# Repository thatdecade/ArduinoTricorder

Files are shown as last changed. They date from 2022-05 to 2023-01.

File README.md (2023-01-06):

# ArduinoTricorder
Interactive Tricorder Prop with real environmental sensors

Based on the original work by lambtor: https://github.com/lambtor/ArduinoTricorder

# Features

* Animated Lights and Sounds, Interactive Menus
* Thermal Camera (MLX90640)
* Climate Sensors: Humidity (SHT31), Temperature and barometric pressure (BMP280)
* Color Sensor and Distance Measurement (APDS9960)
* Microphone (PDM) FFT spectrum
* Auto Sleep when Door is Closed, uses Magnetometer (LIS3MDL)

# Usage

On Power up, the main screen is displayed and the sound effects start.  

* To navigate the info pages, press left or right.  Pressing center goes home.
* To toggle sound effects, hold the left button.
* Close the lid or wait 10 mins to put to sleep, low power mode.  Open the lid or press a button to wake up.

Thermal Camera: To access the video, press the button marked User SW on the Feather board.  If you did not install the thermal camera, the tricorder will display an error message.
Press the center button to return home.

# Part List

TBD

# 3D Printing

The case assembly notes are on printables: https://www.printables.com/model/225964-printability-remix-of-arduino-tricorder

# Wiring Diagram

Battery, Charger Jack, and Power Switch not shown.  See Adafruit Feather nRF52840 Sense docs.

I used a 2500mAh battery, but smaller would work fine too.  1000mAh - 2500mAh is recommended.

arduinotricorder_fritzing_diagram_bb

If you want to change any wires, use the pinmap.h file.  

# Software Setup

Follow the adafruit guide for setting up the Feather nRF52840 board package in Arduino. Then begin installing the libraries.
https://learn.adafruit.com/adafruit-feather-sense/arduino-support-setup

1. Copy the MLX90640_API folder from this repo's libraries folder to your arduino's libraries folder.  If you are unsure where this is, open Preferences from the Arduino File menu and look for the sktechbook location. Mine is My Documents\Arduino\libraries.
1. Install the following lilbraries.  Start with the latest versions.
> * Adafruit NeoPixel version 1.10.6
> * Adafruit TinyUSB Library version 1.7.0
> * Adafruit GFX Library version 1.11.3
> * Adafruit BusIO version 1.14.1
> * Adafruit ST7735 and ST7789 Library 
> * Adafruit APDS9960 Library version 1.2.2
> * Adafruit BMP280 Library version 2.6.6
> * Adafruit Unified Sensor version 1.1.6
> * Adafruit SHT31 Library version 2.2.0
> * nRF52840 PDM - Adafruit Fork version 1.0
> * Adafruit Zero FFT Library version 1.0.4
> * Adafruit LIS3MDL version 1.2.1
> * DFRobotDFPlayerMini version 1.0.5
3. Hit the Compile to test everything is as it should be.  If you get any errors, try switching to the version listed above.
4. Plug in the arduino to USB, and select Adafruit Feather nRF52840 Sense as the board, then select the port.
5. Hit Upload.

If all went well, you should see the display come alive.

# Bugs

* I used D13 for the BIO button input and needed to remove the Arduino's D13 onboard LED.  

On the Adafruit Feather nRF52840 Sense board, D13 is wired to an onboard LED (similar to other arduino boards).  D13 worked at first using INPUT_PULLUP, but eventually stopped working.  I measured the voltage on this pin at 1.9V when the button was unpressed, and 0.2V for pressed.  The nRF52840 requires at least 0.7xVcc to detect a digital high.  1.9V < 2.3V, so the chip thought the button was stuck pressed.  The LED + Resistor and INPUT_PULLUP were creating a voltage clamp at the diode's Forward Voltage.

My fix was unsoldering the D13 LED.  A better fix would be moving the BIO button input wire and reserving D13 as output only.

* Communication with the DFPlayer is inconsistant.

Likely due to me using a clone of the DFPlayer.  Work around is for the arduino to query the status from the DFPlayer every 500ms, then if the player is not playing when it should (or vice versa) we send the play/stop command again.  So if there is a glitch in the audio start / loop / stop, it is fixed quickly.

* Speaker Volume and Screen Flicker, reduce volume and use a larger battery

When the DFPlayer is set to max volume and the tricorder is powered by USB, I noticed the screen flickering from the speaker amp.  Switching to battery, the screen appears ok.

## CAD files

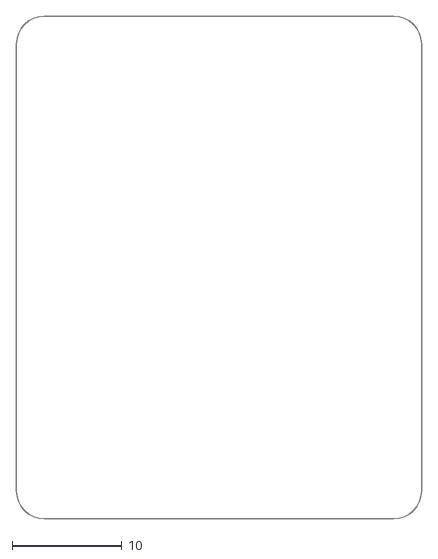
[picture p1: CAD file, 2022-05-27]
ShellModels/Adafruit 1.69in 280x240 Round Rectangle TFT.dxf
36.8 x 45.7

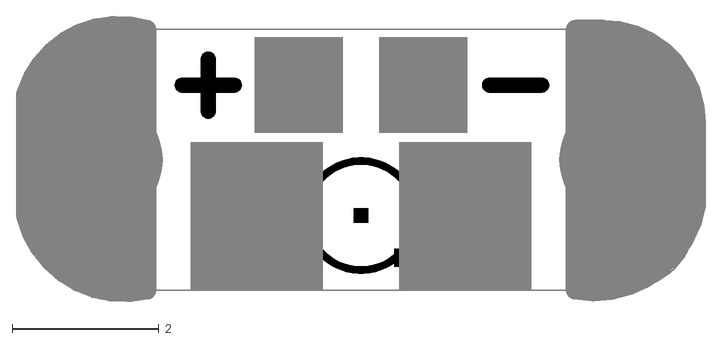
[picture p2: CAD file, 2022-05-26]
ShellModels/Adafruit LED Sequin.dxf
9.40 x 3.90

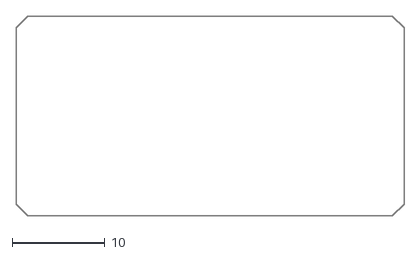
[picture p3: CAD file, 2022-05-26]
ShellModels/ButtonPCB.dxf
41.9 x 21.6

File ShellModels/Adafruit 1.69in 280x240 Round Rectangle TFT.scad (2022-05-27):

margin_for_error = 0.2;

//display_pcb();
//$fn=25;

module display_pcb()
{
    //scale(1.001)
    
    translate([-38.1/2,-45.72/2,1.6/2])
    translate([1.27/2,-1,0])
    difference()
    {
        //OUTLINE
        translate([-1.27,1,0])
        linear_extrude(height = 1.6, center = true, convexity = 10) import("Adafruit 1.69in 280x240 Round Rectangle TFT.dxf");
        
        //HOLES
        //translate([2.25,43.18,0]) cylinder(r=1.2, h=2, center=true);
        //translate([34.0,43.18,0]) cylinder(r=1.2, h=2, center=true);
        //translate([34.0,4.2,0]) cylinder(r=1.2, h=2, center=true);
        //translate([2.25,4.2,0]) cylinder(r=1.2, h=2, center=true);
    }

    //LCD
    fast_rounded_box([30,38,5.4], 4);
}

module fast_rounded_box(size, radius)
{
    height = size[2];
    linear_extrude(height = height)
    projection(cut = true)
    roundedRectangle([size[0]-radius,size[1]-radius,0], radius);
}

module roundedRectangle(size, radius, frontTaper = 0) {
    // https://www.reddit.com/r/openscad/comments/bfx897/comment/elhugtd/
    
    x = size[0];
    y = size[1];
    z = size[2];

    hull() {
        cornerSphere([(-x/2)+(radius/2), (-y/2)+(radius/2) - frontTaper, z], radius);
        cornerSphere([(x/2)-(radius/2), (-y/2)+(radius/2) - frontTaper, z], radius);
        cornerSphere([(-x/2)+(radius/2), (y/2)-(radius/2), z], radius);
        cornerSphere([(x/2)-(radius/2), (y/2)-(radius/2), z], radius);
    }
}

module cornerSphere(location, radius) {
    translate(location) sphere(r=radius);
}

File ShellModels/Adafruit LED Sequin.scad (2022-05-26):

margin_for_error = 0.2;

module led_sequin()
{
    scale(1.01)
    {
        //OUTLINE
        linear_extrude(height = 1.6, center = true, convexity = 10) import("Adafruit LED Sequin.dxf");

        //LED
        translate([0,-0.762,1.6-0.55]) cube([3.2+margin_for_error,1.6+margin_for_error,0.55], center=true);

        //RESISTOR
        translate([0,1.016,1.6-0.55]) cube([1.6+margin_for_error,0.8+margin_for_error,0.55], center=true);

        //WIRES
        translate([-3.556,0,1.6-0.5]) cylinder(d=1,h=1, center=true, $fn=10);
        translate([ 3.556,0,1.6-0.5]) cylinder(d=1,h=1, center=true, $fn=10);
    }
}

//led_sequin();

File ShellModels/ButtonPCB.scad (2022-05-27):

margin_for_error = 0.2;

//button_pcb();


module button_pcb()
{
    scale(1.01)
    difference()
    {
        translate([-41.91/2,-21.59/2,0])
        {
            //OUTLINE
            linear_extrude(height = 1.6, center = true, convexity = 10) import("ButtonPCB.dxf");

            translate([0,0,1.6-0.55])
            {
            //LEDs
            translate([9.525, 14.986,0]) button_side_led();
            translate([22.606,14.986,0]) button_side_led();
            translate([35.56, 14.986,0]) button_side_led();

            //BUTTONS
            translate([9.398, 8.382,0]) button_button();
            translate([22.479,8.382,0]) button_button();
            translate([35.56, 8.382,0]) button_button();

            //WIRES
            translate([39.37,20.32,0]) button_spaced_wire_connector();
            }
        }
        
        //screw holes
        translate([-41.91/2,-21.59/2,0])
        translate([0,0,1.6-0.55])
        {
            translate([16.0655, 14,0]) cylinder(d=3.75, h=4, center=true);
            translate([29.083, 14,0]) cylinder(d=3.75, h=4, center=true);
        }
    }
}

module button_side_led()
{
    cube([3.98+margin_for_error,1.7+margin_for_error,2+margin_for_error], center=true);
}

module button_button()
{
            translate([0,0,+0.5]) cube([11.4+margin_for_error,1.6+margin_for_error,1.6], center=true);
            translate([0,0,1.9]) cube([6+margin_for_error,3.5+margin_for_error,4.57], center=true);
}

module button_spaced_wire_connector()
{
        button_wire_spacing = 2.54;
        translate([-button_wire_spacing*0,0,0]) cylinder(d=1,h=1, center=true, $fn=10);
        translate([-button_wire_spacing*1,0,0]) cylinder(d=1,h=1, center=true, $fn=10);
        translate([-button_wire_spacing*2,0,0]) cylinder(d=1,h=1, center=true, $fn=10);
        translate([-button_wire_spacing*3,0,0]) cylinder(d=1,h=1, center=true, $fn=10);
        translate([-button_wire_spacing*4,0,0]) cylinder(d=1,h=1, center=true, $fn=10);
        translate([-button_wire_spacing*5,0,0]) cylinder(d=1,h=1, center=true, $fn=10);
        translate([-button_wire_spacing*6,0,0]) cylinder(d=1,h=1, center=true, $fn=10);
        translate([-button_wire_spacing*7,0,0]) cylinder(d=1,h=1, center=true, $fn=10);
        translate([-button_wire_spacing*8,0,0]) cylinder(d=1,h=1, center=true, $fn=10);
}

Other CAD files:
ShellModels/tricorder_body.scad
ShellModels/tricorder_hinge.scad

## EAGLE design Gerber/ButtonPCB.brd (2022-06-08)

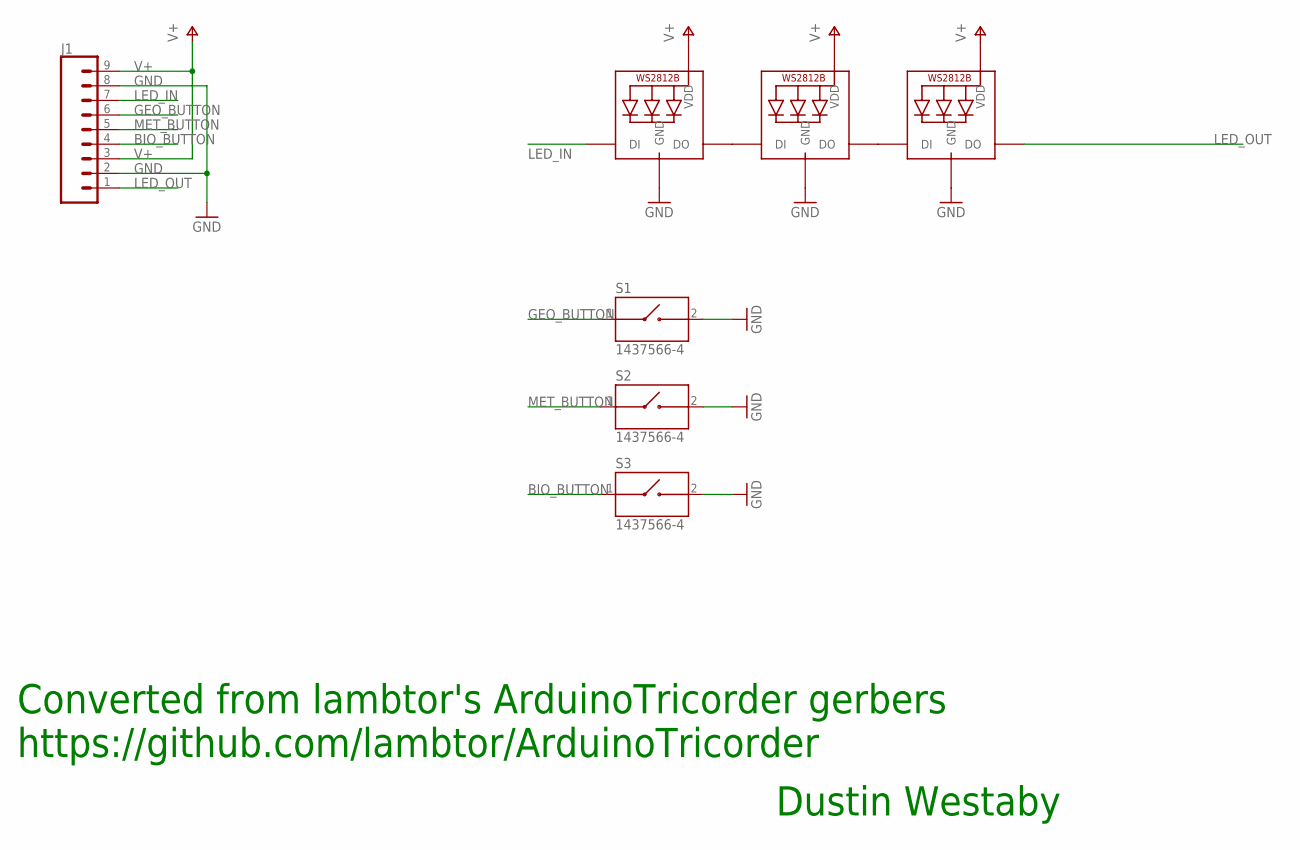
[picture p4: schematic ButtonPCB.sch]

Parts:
J1: CONN_09; 1X09
LED1, LED2, LED3: WS2812B_4020
S1, S2, S3: 1437566-4; SW_1437566-4

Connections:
BIO_BUTTON: J1.4, S3.1
GEO_BUTTON: J1.6, S1.1
GND: J1.2, J1.8, LED1.4 (GND), LED2.4 (GND), LED3.4 (GND), S1.2, S2.2, S3.2
LED_IN: J1.7, LED2.1 (DI)
LED_OUT: J1.1, LED3.3 (DO)
MET_BUTTON: J1.5, S2.1
unnamed: LED1.1 (DI), LED2.3 (DO)
unnamed: LED1.3 (DO), LED3.1 (DI)
V+: J1.3, J1.9, LED1.2 (VDD), LED2.2 (VDD), LED3.2 (VDD)

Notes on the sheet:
Converted from lambtor's ArduinoTricorder gerbers
https://github.com/lambtor/ArduinoTricorder
Dustin Westaby

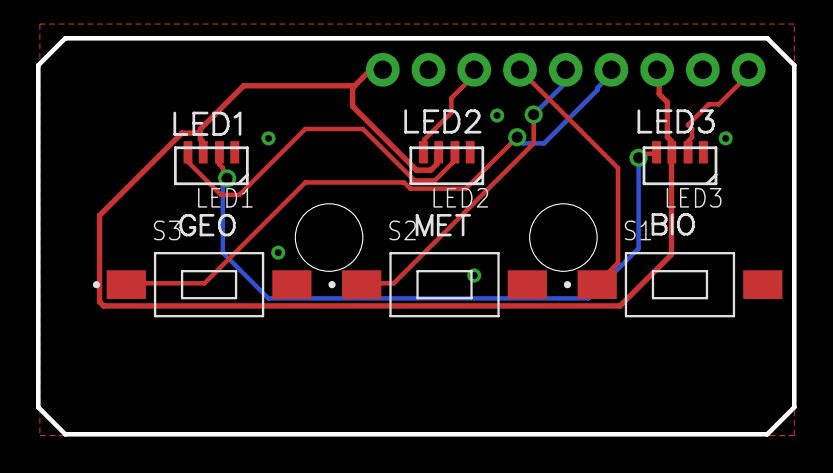
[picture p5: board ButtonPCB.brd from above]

Board: 2 copper layers, 42.0 x 22.0 mm, 7 parts (1 on the bottom side), 9 nets.

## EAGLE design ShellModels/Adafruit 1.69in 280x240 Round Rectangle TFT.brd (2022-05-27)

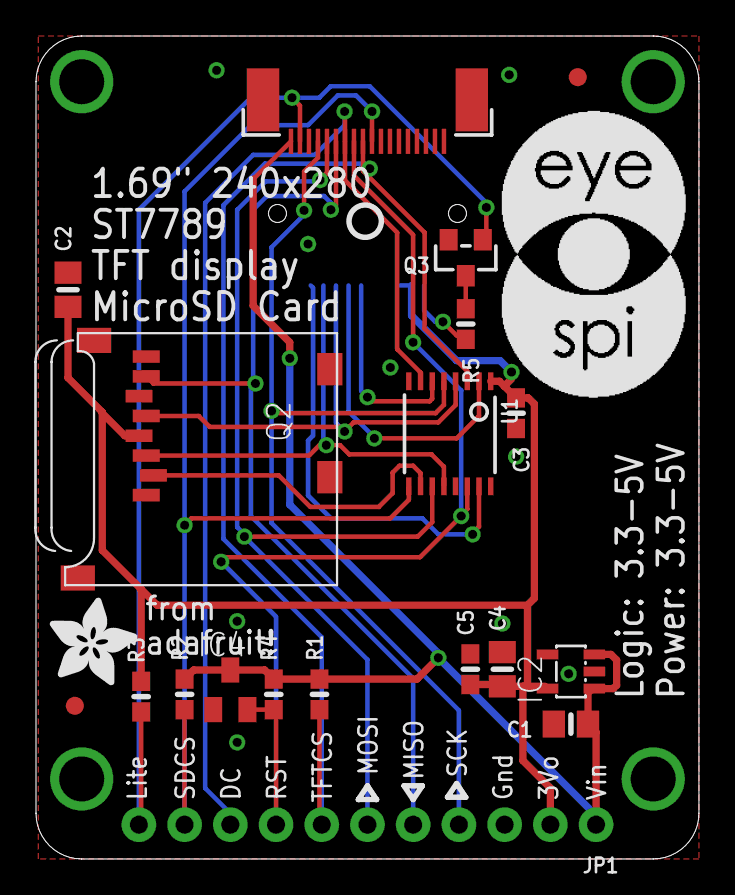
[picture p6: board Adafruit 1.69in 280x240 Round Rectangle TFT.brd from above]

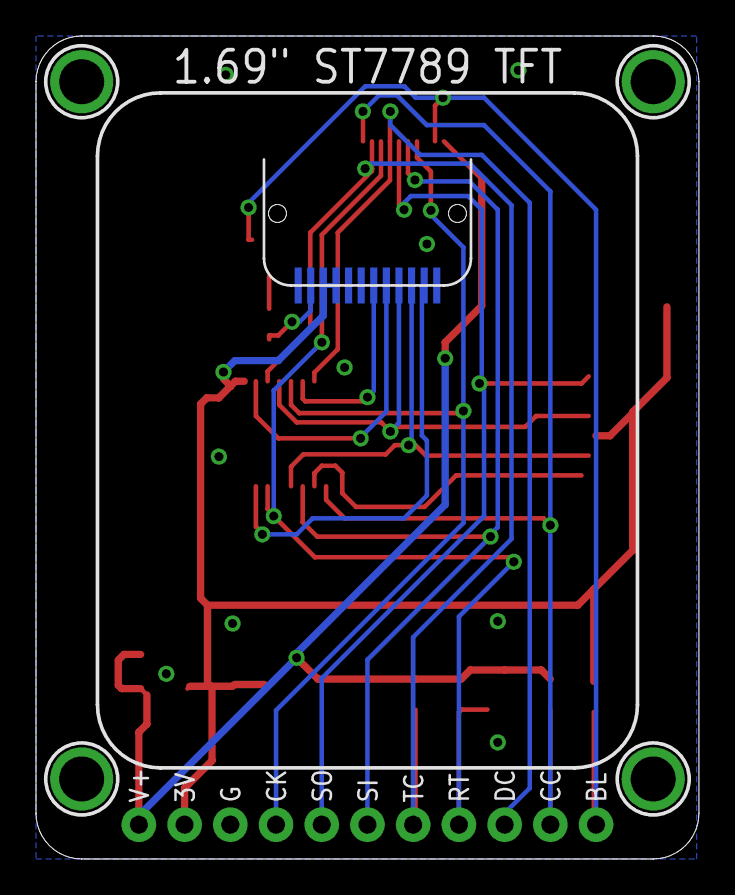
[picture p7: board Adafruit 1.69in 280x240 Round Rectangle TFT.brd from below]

Board: 2 copper layers, 36.8 x 45.7 mm, 27 parts (5 on the bottom side), 19 nets.

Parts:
C1, C2, C4: 10uF; 0805-NO
C3, C5: 0.1uF; 0603-NO
DISP1: DISP_LCD_GENERIC_SPI_1.69_WRAPUNDER; TFT_1.69IN_240X280_12P
IC2: AP2112; SOT23-5L
IC4: APX803-SAG; SOT23
JP1: 1X11_ROUND_76
Q2: MICROSD
Q3: BSS138; SOT23-WIDE
R1, R2, R3, R4: 10K; 0603-NO
R5: 10; 0603-NO
U1: 74HC4050PWR; TSSOP16
U$1: ADAFRUIT_5MM
U$2: PCBFEAT-REV-040
U$4, U$5: FIDUCIAL_1MM
U$7, U$8, U$9, U$10: MOUNTINGHOLE2.5; MOUNTINGHOLE_2.5_PLATED
U$19: EYESPI_LOGO
X1: EYE_SPI_DISPLAY_FLIP; EYE_SPI_DISPLAY_BOTCONTACT

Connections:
+3V3: C2.1, C3.1, C4.1, C5.1, DISP1.3, DISP1.4, IC2.5, JP1.2, Q2.4, R3.2, U1.1
CARDCS: JP1.10, R2.1, U1.9, X1.10
CARDCS_3V: Q2.2, U1.10
GND: C1.2, C2.2, C3.2, C4.2, C5.2, DISP1.1, DISP1.5, DISP1.6, DISP1.12, IC2.2, IC4.1, JP1.3, Q2.6, Q2.MT1, Q2.MT2, Q3.2, U1.8, X1.3, X1.SUPPORT1, X1.SUPPORT2
LEDK: DISP1.2, R5.2
LITE: JP1.11, Q3.1, R3.1, X1.2
MISO: JP1.5, Q2.7, X1.6
MOSI: JP1.6, U1.11, X1.5
MOSI_3V: DISP1.10, Q2.3, U1.12
unnamed: Q3.3, R5.1
SCK: JP1.4, U1.5, X1.4
SCK_3V: DISP1.9, Q2.5, U1.4
TFTCS: JP1.7, R1.1, U1.3, X1.9
TFTCS_3V: DISP1.8, U1.2
TFTDC: JP1.9, U1.7, X1.7
TFTDC_3V: DISP1.7, U1.6
TFTRST: IC4.2, JP1.8, R4.1, U1.14, X1.8
TFTRST_3V: DISP1.11, U1.15
VIN: C1.1, IC2.1, IC2.3, IC4.3, JP1.1, R1.2, R2.2, R4.2, X1.1

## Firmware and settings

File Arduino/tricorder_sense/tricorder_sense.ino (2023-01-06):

#include <Adafruit_NeoPixel.h>
#include <SPI.h>
#include <Adafruit_GFX.h>     // Core graphics library
#include <Adafruit_ST7789.h>  // Hardware-specific library for ST7789
#include <string.h>
#include <Adafruit_APDS9960.h>  //RGB, light, proximity, gesture sensor
#include <Wire.h>
#include <Adafruit_BMP280.h>  //altitude, barometer
#include <Adafruit_SHT31.h>   //temp, humidity
#include <Adafruit_Sensor.h>
#include <PDM.h>              // Microphone
#include <Adafruit_ZeroFFT.h> // Audio spectrum
#include <MLX90640_API.h>     //Thermal Camera
#include <MLX90640_I2C_Driver.h>
#include <Adafruit_LIS3MDL.h> //magnetometer, for door close detection
//#include <Adafruit_LSM6DS33.h> //Accel + Gyro (unused)

#include "pinmap.h" // go here to set your own pin definitions
#include "buttons.h"
#include "menu_navigation.h"
#include "sleep_timer.h"
#include "audio_player.h"

#if defined(USE_TINYUSB)
#include <Adafruit_TinyUSB.h> // for Serial, version 1.7.0
#endif

//comment these out for faster startup and timers
//#define DEBUGSERIAL 1
//#define DEBUGMAGNET_ON_SERIAL 1

 
// need to remove hyphens from header filenames or exception will get thrown
#include "Fonts/lcars15pt7b.h"
#include "Fonts/lcars11pt7b.h"

#define SCAN_LED_BRIGHTNESS   (32)

#define NEOPIXEL_BRIGHTNESS     (64)

//ledPwrStrip - cover and door pixels.  This structure defines the order of the LEDs on the string
typedef enum
{ //re-arrange as need based on your wiring
  PWR_PIXEL_POSITION = 0, // POWER LED
  GEO_PIXEL_POSITION,     // BUTTON LED
  MET_PIXEL_POSITION,     // BUTTON LED
  BIO_PIXEL_POSITION,     // BUTTON LED
  ID_PIXEL_POSITION,      // DOOR LED
  EMRG_PIXEL_POSITION,    // DOOR LED

  POWERSTRIP_LED_COUNT, //must be last
} strip_led_positions;

//ledBoard - front pixels
#define BOARD_PIXEL_POSITION 0

//system os version #. max 3 digits
#define DEVICE_VERSION      "0.94"

//theme definition: 0 = TNG, 1 = DS9, 2 = VOY
#define UX_THEME                  (0)

#define THERMAL_CAMERA_PORTRAIT   (1)

//uncomment this line to have raw magnetometer z value displayed on home screen
//#define MAGNET_DEBUG

//the -700 threshold was based on resolution of 10, or 1024 max
//-10000 is based on the analog resolution required by battery pin (-32768 to 32768 range)
//this is intended for the z index reading of magnetometer (negative means field is below the board)
#define mnMagnetSleepThreshold -10000
#define mnMagnetAproachingThreshold 0

#if UX_THEME == 0
  // TNG colors here
  #define color_SWOOP       0xF7B3
  #define color_MAINTEXT    0x9E7F
  //#define color_MAINTEXT    0xC69F
  #define color_LABELTEXT   0x841E
  #define color_HEADER      0xFEC8
  #define color_TITLETEXT   0xFEC8
  //196,187,145
  #define color_LABELTEXT2  0xC5D2
  //204,174,220
  #define color_LABELTEXT3  0xCD7B
  #define color_LABELTEXT4  0xEE31
  #define color_LEGEND      0x6A62
  //210,202,157
  #define color_FFT         0xDEB5
#elif UX_THEME == 1
  // ds9
  #define color_SWOOP       0xD4F0
  #define color_MAINTEXT    0xBD19
  #define color_LABELTEXT   0x7A8D
  #define color_HEADER      0xECA7
  #define color_TITLETEXT   0xC3ED
  //to-do: find fitting options for these to mesh with ds9
  #define color_LABELTEXT2  0xC5D2
  #define color_LABELTEXT3  0xCD7B
  #define color_LABELTEXT4  0xEE31
  #define color_LEGEND      0x6A62
  #define color_FFT         0xDEB5
#elif UX_THEME == 2
  // voy
  #define color_MAINTEXT    0x9E7F
  #define color_SWOOP       0x7C34
  #define color_LABELTEXT   0x9CDF
  #define color_HEADER      0xCB33
  #define color_TITLETEXT   0xFFAF
  //to-do: find fitting options for these to mesh with voy
  #define color_LABELTEXT2  0xC5D2
  #define color_LABELTEXT3  0xCD7B
  #define color_LABELTEXT4  0xEE31
  #define color_LEGEND      0x6A62
  #define color_FFT         0xDEB5
#endif

#define color_REDLABELTEXT     0xE000
#define color_REDDARKLABELTEXT 0x9800
#define color_REDDATATEXT      0xDEFB

//use labeltext3 for servo ltpurple
#define color_SERVOPINK     0xFE18
#define color_SERVOPURPLE   0x83B7


#define RGBto565(r,g,b) ((((r) & 0xF8) << 8) | (((g) & 0xFC) << 3) | ((b) >> 3))

Adafruit_NeoPixel ledPwrStrip(POWERSTRIP_LED_COUNT, NEOPIXEL_CHAIN_DATAPIN, NEO_GRB + NEO_KHZ800);
Adafruit_NeoPixel ledBoard(1, NEOPIXEL_BOARD_LED_PIN, NEO_GRB + NEO_KHZ800);

uint32_t neoPixelBlack  = ledPwrStrip.Color(   0,   0,   0);
uint32_t neoPixelBlue   = ledPwrStrip.Color(   0,   0, 128);
uint32_t neoPixelGreen  = ledPwrStrip.Color(   0, 128,   0);
uint32_t neoPixelYellow = ledPwrStrip.Color( 112, 128,   0);
uint32_t neoPixelOrange = ledPwrStrip.Color( 128,  96,   0);
uint32_t neoPixelRed    = ledPwrStrip.Color( 128,   0,   0);
uint32_t neoPixelWhite  = ledPwrStrip.Color( 255, 255, 255);

//  2.0" IS THE BOARD - this call uses hardware SPI
Adafruit_ST7789   tft = Adafruit_ST7789(TFT_CS, TFT_DC, TFT_RST);
//create sensor objects
Adafruit_APDS9960 oColorSensor;
Adafruit_BMP280   oTempBarom;
Adafruit_SHT31    oHumid;
Adafruit_LIS3MDL  oMagneto;
paramsMLX90640    moCameraParams;

int mnCurrentProfileRed   = 0;
int mnCurrentProfileGreen = 0;
int mnCurrentProfileBlue  = 0;

String msCurrentProfileName = "";

int mnEMRGCurrentStrength =   8;

bool mbLEDIDSet = false;

/* Timer Values */
#define POWER_LED_INTERVAL        8000  //power interval doesn't need to check more than every 30 seconds
#define BOARD_LED_INTERVAL        5000
#define ID_LED_INTERVAL           1000
#define EMRG_LED_INTERVAL           33  //30Hz
#define EMRG_LED_BREATHING_RATE   1500
#define BUTTON_LED_INTERVAL        100

#define RGB_SCAN_INTERVAL         5000
#define MIC_READ_INTERVAL         3000
#define CLIMATE_SCAN_INTERVAL     2000
#define MAGNET_READ_INTERVAL      1000
#define HOME_UPDATE_INTERVAL      1000
#define AUDIO_UPDATE_RATE          500
#define BOARD_RED_LED_INTERVAL     350
#define BOARD_BLUE_LED_INTERVAL    250
#define LEFT_SCANNER_LED_INTERVAL  200
#define DISPLAY_UPDATE_RATE        100 // 10hz
#define THERMAL_CAMERA_INTERVAL     50 // twice per display refresh
#define SERVO_DRAW_INTERVAL         38
#define BAR_DRAW_INTERVAL            9
//17 ms is 60fps. setting this to 120fps, at least for initial crawl

/* EMRG LED Animation */
#define EMRG_MIN_BRIGHTNESS   50
#define EMRG_MAX_BRIGHTNESS  212
#define EMRG_BREATH_INCREMENT ((EMRG_MAX_BRIGHTNESS - EMRG_MIN_BRIGHTNESS) / (EMRG_LED_BREATHING_RATE / EMRG_LED_INTERVAL))
bool mbEMRGdirection = false;

int mnLeftLEDCurrent = 0;

/* Scroll wheel colors and names */
#define NUMBER_ID_COLORS 8
                    //colors range is purple > blue > green > yellow > orange > red  > pink > white
const uint32_t mnIDLEDColorscape[NUMBER_ID_COLORS] = {0x8010, 0x0010, 0x0400, 0x7C20,  0x8300,  0x8000,0x8208,0x7C30};
const String marrProfiles[] = {"ALPHA","BETA","GAMMA","DELTA","EPSILON","ZETA","ETA","THETA"};
//you can reverse order if the pot was wired backwards

const uint16_t mnThermalCameraLabels[] = {0xD6BA,0xC0A3,0xD541,0xD660,0x9E02,0x0458,0x89F1};

/* Module stuff */
bool color_sensor_initialized  = false;
bool mbTempInitialized         = false;
bool mbHumidityInitialized     = false;
bool mbMicrophoneStarted       = false;
bool Thermal_Camera_Started    = false;
bool magnet_sensor_initialized = false;

int mnRGBCooldown = 0;

//temperature, humidity, pressure
//Average sea-level pressure is 1013.25 mbar

float mfTempC = 0.0;
float mfTempK = 0.0;
float mfHumid = 0.0;

int mnBarom   = 0;

int mnTempTargetBar   =  0;
int mnTempCurrentBar  =  0;
int mnHumidTargetBar  =  0;
int mnHumidCurrentBar =  0;
int mnBaromTargetBar  =  0;
int mnBaromCurrentBar =  0;
int mnClimateBarStart = 62;

unsigned long mnLastTempBar  = 0;
unsigned long mnLastBaromBar = 0;
unsigned long mnLastHumidBar = 0;

bool mbHumidBarComplete = false;
bool mbTempBarComplete = false;
bool mbBaromBarComplete = false;

int marrScaleNotches[] = {123, 185, 247};

bool mbMicrophoneRedraw = false;

extern PDMClass PDM;

//mic sample rate is hertz, all samples are stored as 16 bit data.
//number of samples must be double the desired resolution, and be a base 2 number
//16k hertz -> 0-8k hertz max audio range captured
#define MIC_SAMPLESIZE         256
//16k is the ONLY SUPPORTED SAMPLE RATE!
//#define MIC_SAMPLERATE        16000
//#define MIC_AMPLITUDE         1000  // Depending on audio source level, you may need to alter this value. Can be used as a 'sensitivity' control.
//#define DECIMATION              64
//#define FFT_REFERENCELINES      16
//#define FFT_MAX                150
#define FFT_BINCOUNT            16
#define FFT_BARHEIGHTMAX        64

#define GRAPH_OFFSET            10
#define GRAPH_WIDTH  (tft.width() - 3)
#define GRAPH_HEIGHT (tft.height() - GRAPH_OFFSET)

long MIC_SAMPLERATE = 16000;
//int32_t mnMicVal    =     0;

bool mbMicMaxRefresh = false;
short mnarrSampleData[MIC_SAMPLESIZE];
// number of samples read
volatile int mnSamplesRead = 0;
//double mdarrActual[MIC_SAMPLESIZE];
//double mdarrImaginary[MIC_SAMPLESIZE];
int mnMaxDBValue = 0;

// a windowed sinc filter for 44 khz, 64 samples
//uint16_t marrSincFilter[DECIMATION] = {0, 2, 9, 21, 39, 63, 94, 132, 179, 236, 302, 379, 467, 565, 674, 792, 920, 1055, 1196, 1341, 1487, 1633, 1776, 1913, 2042, 2159, 2263, 2352, 2422, 2474, 2506, 2516, 2506, 2474, 2422, 2352, 2263, 2159, 2042, 1913, 1776, 1633, 1487, 1341, 1196, 1055, 920, 792, 674, 565, 467, 379, 302, 236, 179, 132, 94, 63, 39, 21, 9, 2, 0, 0};

unsigned long mnLastMicRead = 0;
//decibel estimation every 3 seconds
short mCurrentMicDisplay[FFT_BINCOUNT] = {0,0,0,0,0,0,0,0,0,0,0,0,0,0,0,0};
short mTargetMicDisplay[FFT_BINCOUNT] = {0,0,0,0,0,0,0,0,0,0,0,0,0,0,0,0};

const uint8_t mbCameraAddress = 0x33;

#define TA_SHIFT 8

//temperature cutoffs are given in celsius. -12C => -10F
int MIN_CAMERA_TEMP = 20;
int MAX_CAMERA_TEMP = 35;

//need array length of 768 as this is 32*24 resolution
float mfarrTempFrame[768];
float mfTR = 0.0;
float mfTA = 0.0;
float mfCameraEmissivity = 0.95;

//this interval caps draw and thermal data frame rates. camera data will run slower than 30fps, but this throttle is needed to allow button press event polling
//50ms -> 20fps cap
//this must be less than 10 for all data to be displayed on 320x240.
//this scales display window to 256 x 192, a border of 24px all around
// if thermal camera is rotated 90 degrees, can change thermal to square viewport
// portrait hardware could be overall benefit, with viewport 216x216 (24*9)
uint16_t mnThermalPixelWidth  = (THERMAL_CAMERA_PORTRAIT == 1) ?  9 :  8;
uint16_t mnThermalPixelHeight = (THERMAL_CAMERA_PORTRAIT == 1) ?  9 :  8;
uint8_t mnCameraDisplayStartX = (THERMAL_CAMERA_PORTRAIT == 1) ? 52 : 32;
uint8_t mnCameraDisplayStartY = (THERMAL_CAMERA_PORTRAIT == 1) ? 12 : 24;
//uint8_t mnCameraDisplayStartY = 0;

//16hz ~= 16fps
//while this is editable, it's probably not worth the time to decode and re-encode just to convert it to the desired LCARS color scheme
//lowest value is super dark purple: RGB 78,0,128
//highest value (0xF800) was 255,0,0
//2021.07.26  expanding color map to go from red to white for top-most end of temp range supported
const uint16_t mnarrThermalDisplayColors[] = {0x480F, 0x400F,0x400F,0x400F,0x4010,0x3810,0x3810,0x3810,0x3810,0x3010,0x3010,
0x3010,0x2810,0x2810,0x2810,0x2810,0x2010,0x2010,0x2010,0x1810,0x1810,0x1811,0x1811,0x1011,0x1011,0x1011,0x0811,0x0811,0x0811,0x0011,0x0011,
0x0011,0x0011,0x0011,0x0031,0x0031,0x0051,0x0072,0x0072,0x0092,0x00B2,0x00B2,0x00D2,0x00F2,0x00F2,0x0112,0x0132,0x0152,0x0152,0x0172,0x0192,
0x0192,0x01B2,0x01D2,0x01F3,0x01F3,0x0213,0x0233,0x0253,0x0253,0x0273,0x0293,0x02B3,0x02D3,0x02D3,0x02F3,0x0313,0x0333,0x0333,0x0353,0x0373,
0x0394,0x03B4,0x03D4,0x03D4,0x03F4,0x0414,0x0434,0x0454,0x0474,0x0474,0x0494,0x04B4,0x04D4,0x04F4,0x0514,0x0534,0x0534,0x0554,0x0554,0x0574,
0x0574,0x0573,0x0573,0x0573,0x0572,0x0572,0x0572,0x0571,0x0591,0x0591,0x0590,0x0590,0x058F,0x058F,0x058F,0x058E,0x05AE,0x05AE,0x05AD,0x05AD,
0x05AD,0x05AC,0x05AC,0x05AB,0x05CB,0x05CB,0x05CA,0x05CA,0x05CA,0x05C9,0x05C9,0x05C8,0x05E8,0x05E8,0x05E7,0x05E7,0x05E6,0x05E6,0x05E6,0x05E5,
0x05E5,0x0604,0x0604,0x0604,0x0603,0x0603,0x0602,0x0602,0x0601,0x0621,0x0621,0x0620,0x0620,0x0620,0x0620,0x0E20,0x0E20,0x0E40,0x1640,0x1640,
0x1E40,0x1E40,0x2640,0x2640,0x2E40,0x2E60,0x3660,0x3660,0x3E60,0x3E60,0x3E60,0x4660,0x4660,0x4E60,0x4E80,0x5680,0x5680,0x5E80,0x5E80,0x6680,
0x6680,0x6E80,0x6EA0,0x76A0,0x76A0,0x7EA0,0x7EA0,0x86A0,0x86A0,0x8EA0,0x8EC0,0x96C0,0x96C0,0x9EC0,0x9EC0,0xA6C0,0xAEC0,0xAEC0,0xB6E0,0xB6E0,
0xBEE0,0xBEE0,0xC6E0,0xC6E0,0xCEE0,0xCEE0,0xD6E0,0xD700,0xDF00,0xDEE0,0xDEC0,0xDEA0,0xDE80,0xDE80,0xE660,0xE640,0xE620,0xE600,0xE5E0,0xE5C0,
0xE5A0,0xE580,0xE560,0xE540,0xE520,0xE500,0xE4E0,0xE4C0,0xE4A0,0xE480,0xE460,0xEC40,0xEC20,0xEC00,0xEBE0,0xEBC0,0xEBA0,0xEB80,0xEB60,0xEB40,
0xEB20,0xEB00,0xEAE0,0xEAC0,0xEAA0,0xEA80,0xEA60,0xEA40,0xF220,0xF200,0xF1E0,0xF1C0,0xF1A0,0xF180,0xF160,0xF140,0xF100,0xF0E0,0xF0C0,0xF0A0,
0xF080,0xF060,0xF040,0xF020,0xF800
//};
,0xF841,0xF8A2,0xF8E3,0xF945,0xF986,0xF9E7,0xFA28,0xFA8A,0xFACB,0xFB2C,0xFB6D,0xFBCF,0xFC10,0xFC71,0xFCB2,0xFD14,0xFD55,0xFDB6,0xFDF7,0xFD59
,0xFE9A,0xFEFB,0xFF3C,0xFF9E};

//graphs should take 3 seconds for full draw cycle-> 3000 / 80 lines

unsigned long mnServoLastDraw = 0;

uint8_t mnCurrentServoGraphPoint = 0;

//establish graph values
const uint8_t mnarrServoGraphData[] = {3,7,10,12,13,14,14,14,13,12,10,7,4,4,6,8,11,13,14,15,15,15,15,14,13,
                  12,10,8,7,6,4,3,2,2,2,3,4,6,8,9,11,12,12,12,11,10,9,7,5,3,3,3,5,7,10,
                  11,11,12,12,12,11,11,10,9,9,9,8,8,8,8,7,6,5,5,5,5,4,3,2,2,2};

enum
{
  TEMP_CLIMATE_BARGRAPH = 0,
  HUMID_CLIMATE_BARGRAPH,
  BAROM_CLIMATE_BARGRAPH,
};

void setup() 
{
#ifdef DEBUGSERIAL
  Serial.begin(115200);
  while ( !Serial )
  {
    delay(10); //wait up to 2 seconds for serial to connect
    if (millis() > 2000) break;
  }
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
void loop()
{
  static unsigned long process_buttons_timer = 0;

  if (millis() > process_buttons_timer + BUTTON_SCAN_RATE_MILLIS)
  {
    process_buttons_timer = millis();

    //scan buttons and change system mode
    poll_input_switches();
    process_menu_selection(); // <-- changes software_state
  }

  //check for other system state changes (sleep / interrupt flags)
  //TBD
  check_for_sleep();

  //run processes (sensors, displays, lights, etc)
  process_schedule();
}

void process_schedule()
{
  static unsigned long process_display_timer = 0;
  static unsigned long process_audio_timer = 0;
  static byte last_state = INITILIZATION;
  
  //these are the "do once" things when the mode changes
  if (last_state != get_software_state())
  {
#if defined(DEBUGSERIAL)
      Serial.print("Current State: ");
      Serial.print(get_software_state());
      Serial.print(", Last State: ");
      Serial.println(last_state);
#endif
    reset_sleep_timer();
    reset_drawing_globals();
    update_menu_displayed(); // side effect: INITILIZATION -> MAIN_SCREEN
    update_sound(true);
    RunNeoPixelColor(true) ;
    
    //save last_state at end. Allows smooth init->main transition
    last_state = get_software_state();
  }
  
  //do these on a schedule
  if (millis() > process_display_timer + DISPLAY_UPDATE_RATE)
  {
    process_display_timer = millis();
    refresh_display_data();
  }

  if (millis() > process_audio_timer + AUDIO_UPDATE_RATE)
  {
    process_audio_timer = millis();
    update_sound(false);
  }

  //do these when not sleeping
  if(SYSTEM_NO_CHANGE_MODES < get_software_state())
  {
    //update lights
    RunNeoPixelColor(false);
    RunLeftScanner();
    RunBoardLEDs();
  }
}


void check_for_sleep() 
{
  static unsigned long mnLastMagnetCheck = 0;
  int nCurrentMagnetZ = 0;
  static int nLastMagnetZ = 0;

  //if magnet read in Z direction is over a threshold, trigger sleep.
  //use MAGNET_DEBUG to check this first in the loop, as everything else depends on it
  //magnet from speaker throws z = ~ +14000, no magnets has z idle at ~ -500
  //use z > 5000 ?
  //all analogRead actions depend on resolution setting - changing this will screw with battery % readings

  //read at set 1Hz interval
  // if magnet is sensed approaching then update at 10Hz
  if ( ((millis() - mnLastMagnetCheck) > MAGNET_READ_INTERVAL ) ||
       ( (nLastMagnetZ < mnMagnetAproachingThreshold ) && ((millis() - mnLastMagnetCheck) > 100 ))
     )
  {
#if defined(DEBUGSERIAL) && defined(DEBUGMAGNET_ON_SERIAL)
      Serial.print("Last Magnet Value: ");
      Serial.print(nLastMagnetZ);
      Serial.print(" < Threshold: ");
      Serial.println((mnMagnetAproachingThreshold));
#endif
#ifndef MAGNET_DEBUG
    if (magnet_sensor_initialized) 
    {
      mnLastMagnetCheck = millis();
      
      oMagneto.read();
      //need tests with speaker above and door magnet below - may require testing within assembled shell
      //magnet function modification needs to use a massive drop as the sleep trigger.
      nCurrentMagnetZ = oMagneto.y;
    }
#endif
    
#if defined(DEBUGSERIAL) && defined(DEBUGMAGNET_ON_SERIAL)
      Serial.print("Sleep timer: ");
      Serial.println(check_sleep_timer());
      Serial.print("Magnet Value: ");
      Serial.print(nCurrentMagnetZ);
      Serial.print(" < Threshold: ");
      Serial.println(mnMagnetSleepThreshold);
#endif

    // go to sleep if:
    // - no button interaction for 10 minutes
    // - door is closed 
    if ( ( (check_sleep_timer()) ||
           (nCurrentMagnetZ < mnMagnetSleepThreshold) ) )
    {
      if (get_software_state() > SYSTEM_NO_CHANGE_MODES)
      {
#ifdef DEBUGSERIAL
        Serial.println("Going to sleep");
#endif
        //if not already sleeping, send to sleep
        set_software_state(GO_TO_SLEEP);
      }
    }
    else
    // - button interaction in the last 10 minutes
    // - door is open 
    {
      if(get_software_state() < SYSTEM_NO_CHANGE_MODES)
      {
#ifdef DEBUGSERIAL
        Serial.println("Wake up");
#endif
        //only go to init if we were sleeping
        set_software_state(INITILIZATION);
      }
    }
    
    //magnet was read, update last
    nLastMagnetZ = nCurrentMagnetZ;
  }
}

void update_menu_displayed()
{
  //only call this once per menu change
  
  switch(get_software_state())
  {
    case INITILIZATION:
      ActiveMode(); // side effect: INITILIZATION -> MAIN_SCREEN
      //no break here, allow to continue into MAIN_SCREEN
    case MAIN_SCREEN:
      display_home_screen();
      break;
    case GO_TO_SLEEP:
      SleepMode();
      break;
    case RGB_SCREEN:
      display_RGB_screen();
      break;
    case CLIMATE_SCREEN:
      display_climate_screen();
      break;
    case MICROPHONE_SCREEN:
      display_micrphone_screen();
      break;
    case BATTERY_SCREEN:
      //TBD
      set_software_state(MAIN_SCREEN); //go home on unused menu
      break;
    case HIDDEN_THERMAL_SCREEN:
      display_hidden_thermal_screen();
      break;
    case HIDDEN_TOM_SERVO_SCREEN:
      //ActivateTomServo();
      set_software_state(MAIN_SCREEN); //go home on unused menu
      break;
    case HIDDEN_LIGHTING_DETECTOR_SCREEN:
      //TBD
      set_software_state(MAIN_SCREEN); //go home on unused menu
      break;
    default:
      //SLEEPING
      break;
  }
}

void RunNeoPixelColor(bool force_update) 
{
  static unsigned long mnLastUpdatePower = 0;
  static unsigned long mnLastUpdateIDLED = 0;
  static unsigned long mnLastUpdateEMRG  = 0;
  static unsigned long mnLastUpdateBUTTON = 0;

  //power & board color enumerator: blue = 4, green = 3, yellow = 2, orange = 1, red = 0
  static int  next_PWR_color   = 4;
  static int  next_BOARD_color = 4;
  
  static unsigned long last_update_board_led_timestamp = 0;
  unsigned long current_time = millis();
  
  uint16_t nScrollerValue;
  uint16_t nTempColor;

  uint8_t software_state = get_software_state();
  
  if(force_update)
  {
    //reset timers
    mnLastUpdatePower = 0;
    mnLastUpdateEMRG  = 0;
    mnLastUpdateIDLED = 0;
    mnLastUpdateBUTTON = 0;
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

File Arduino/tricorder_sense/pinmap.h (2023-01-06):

/*
 * pinmap.h
 *
 *  Created on: Jan 6, 2023
 *      Author: Dustin Westaby
 */

#ifndef INC_PINMAP_H_
#define INC_PINMAP_H_

/*
 Full arduino pinout for this board is here:
 https://github.com/adafruit/Adafruit_nRF52_Arduino/blob/master/variants/feather_nrf52840_sense/variant.h

  List of Hardware
   - Adafruit Feather nRF52840 Sense
   - LCD
   - Audio FX
   - Neopixels
   - Buttons
   - Sequin LEDs

  I2C OnBoard
  Addr  IRQ  Chip      Type            
  0x61   D3  LSM6DS33  Gyro + Accel   
  0x1C       LIS3MDL   Magnetometer   
  0x44       SHT30     Humidity       
  0x77       BMP280    Temp + Pressure  
  0x39  D36  APDS9960  Light + Gesture + Proximity    
  
  I2C OffBoard
  0x33       MLX90640  Thermal Camera
  
  Pin Assignements
  Pin   Function Device
   A0   Input    Scroll Wheel (Library)
   A2   Output   Left LED Scanner (ALPHA)
   A3   Output   Left LED Scanner (BETA)
   A4   Output   Left LED Scanner (GAMMA)
   A5   Output   Left LED Scanner (DELTA)
   A6   Input    VOLTAGE_MONITOR 
   D4   Output   Board Blue LED
   D5   DC       TFT
   D6   CS       TFT
   D7   Input    Board Button (Camera)
   D8   Data     Board NeoPixels (Front Camera Flash)
   D9   Output   PWM Backlight Control (pull down to turn the backlight off)
   MO   MOSI     TFT
  SCK   SCK      TFT
   RX   Output   DFPlayer TX
   TX   Output   DFPlayer RX
  D10   Data     Cover NeoPixels (PWR, ID, EMRG)
  D11   Input    GEO Button (Left)
  D12   Input    MET Button (Center)
  D13   Input    BIO Button (Right)
  D13   Output   Board Red LED (Unsolder and remove this LED from the feather board or move BIO Button input)
  En    VREG     Enable Power Switch (Short to Ground for OFF)  
  SCL   I2C      Thermal Camera
  SDA   I2C      Thermal Camera
  
  -------------------------------------
  
  Adafruit defines physically labeled pin D2 as pin 2 in its header file, but it does not respond when set as an input by default.
  you will need to modify system_nrf52840.c file by adding
  #define CONFIG_NFCT_PINS_AS_GPIOS (1)
  YOU WILL SEE THIS CONSTANT REFERENCED IN THAT FILE, with compiler-conditional logic around it to actually free up the NFC pins, 
  but only if that constant exists in that file

  -------------------------------------
  
 */
 
/* ************************* */
/* Buttons */
/* ************************* */
#define GEO_BUTTON_1_PIN        (11) // GEO
#define MET_BUTTON_2_PIN        (12) // MET
#define BIO_BUTTON_3_PIN        (13) // BIO
#define CAM_BUTTON_BOARD        (PIN_BUTTON1)  // PIN_BUTTON1 - CAMERA / Board Button

/* ************************* */
/* Scroll Wheel */
/* ************************* */
//only need 1 pin for potentiometer / scroller input. both poles need to be wired to GND and 3v - order doesn't matter
#define PIN_SCROLL_INPUT      PIN_A0

/* ************************* */
/* Lights */
/* ************************* */
#define SCAN_LED_PIN_1        PIN_A2
#define SCAN_LED_PIN_2        PIN_A3
#define SCAN_LED_PIN_3        PIN_A4
#define SCAN_LED_PIN_4        PIN_A5

//neopixel power LED. must use an unreserved pin for this.  PWR, ID, EMRG all use this pin
#define NEOPIXEL_CHAIN_DATAPIN  (10)

// built-in pins: D4 = blue conn LED, 8 = neopixel on board, D13 = red LED next to micro usb port
// commented out lines are pre-defined by the adafruit board firmware
#define NEOPIXEL_BOARD_LED_PIN   (8)

/* ************************* */
/* LCD */
/* ************************* */
// For the breakout board, you can use any 2 or 3 pins.
// These pins will also work for the 1.8" TFT shield.
//need to use pin 6 for TFT_CS, as pin 20 is analog 7. analog 7 is the only way to get current voltage, which is used for battery %

//MISO is not required for screen to work - this is used by mem card only?
#define TFT_CS                (6)
// SD card select pin
//#define SD_CS       11  //- can't use pin 4 as that is for blue connection led
#define TFT_RST               -1  //disabled
#define TFT_DC                (5)
#define USE_SD_CARD           (0)
#define TFT_BACKLIGHT         (9)

/* ************************* */
/* Misc */
/* ************************* */
//pin 9 is free, as pin_a6 is for vbat and is otherwise known as digital 20
 //INPUT_POWER_PIN. 
 //mnRF52840 is not 5V tolerance, max analog-in is VCC+0.3V or 3.9V, whichever is lower.  
 // The adafruit sense board has a hardwired 50% voltage divider.
#define VOLT_PIN              PIN_A6   

//buttons are defined in buttons.h

//#define PIN_NEOPIXEL         8
//#define BOARD_REDLED_PIN    13
//#define BOARD_BLUELED_PIN    4
//#define LED_RED             13
//#define LED_BLUE             4

#endif /* INC_PINMAP_H_ */

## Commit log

2022-05-23 Converted to eagleCAD
    [ButtonPCB.brd, ButtonPCB.sch]
2022-05-25 Basic body outline. Work in progress
    [tricorder_body.scad]
2022-05-25 Swapped to smd buttons that I like.
    [ButtonPCB.brd, ButtonPCB.sch]
2022-05-26 Some progress on the control panel
    [tricorder_body.scad]
2022-05-26 circuit board models
    [Adafruit LED Sequin.dxf, Adafruit LED Sequin.scad, ButtonPCB.dxf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]
2022-05-26 Added popouts to hold the panels in place before gluing
    [tricorder_body.scad]
2022-05-26 Added screw hole mounts to button pcb
    [ButtonPCB.brd, tricorder_body.scad]
2022-05-27 lcd model
    [Adafruit 1.69in 280x240 Round Rectangle TFT.brd, Adafruit 1.69in 280x240 Round Rectangle TFT.dxf, Adafruit 1.69in 280x240 Round Rectangle TFT.scad]
2022-05-27 Added lcd bezel
    [ButtonPCB.brd, ButtonPCB.scad, tricorder_body.scad]
2022-05-31 Restored magnet sleep mode, moved neopixel animation controls to own function.
2022-05-31 added sleep timer, narrowed ifdefs around magnet code, moved audio updates to own function
2022-05-31 Menu navigation is based on current screen
2022-05-31 Wiring Notes
2022-06-01 minor updates, notes
    [ButtonPCB.brd, ButtonPCB.sch, tricorder_body.scad]
2022-06-08 Insert-able hinge, for prettier print
    [tricorder_hinge.scad]
2023-01-02 Debugged buttons, menus, and most lights.
2023-01-03 Debugged rgb sensor
2023-01-04 Merged the various LED strip functions, fixed EMRG
    [tricorder_sense.ino]
2023-01-04 Fixed detection of camera connected / disconnected
    [tricorder_sense.ino]
2023-01-05 Hold left button to toggle audio on/off
2023-01-06 Moved pin assignments to pinmap.h

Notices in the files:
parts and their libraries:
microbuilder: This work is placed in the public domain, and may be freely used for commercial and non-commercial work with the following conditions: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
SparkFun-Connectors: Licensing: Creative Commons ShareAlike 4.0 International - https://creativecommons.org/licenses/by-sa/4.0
